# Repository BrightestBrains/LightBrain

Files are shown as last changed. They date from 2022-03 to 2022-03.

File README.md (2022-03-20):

# LightBrain

## Overview

The initial motivation was to develop a compact and relatively versatile light control device. Communicating with colleagues interested in electronics, I made a few design decisions so that the functionality would meet a number of requests: wide power supply voltages, protection, buttons, DMX support, shifted ouputs.

* ESP32-WROOM module
* four level shifted outputs
* 6-30V protected power input
* RS485 chip (DMX Support)
* Convinent buttons and user LED
* Very handy WAGO spring terminals

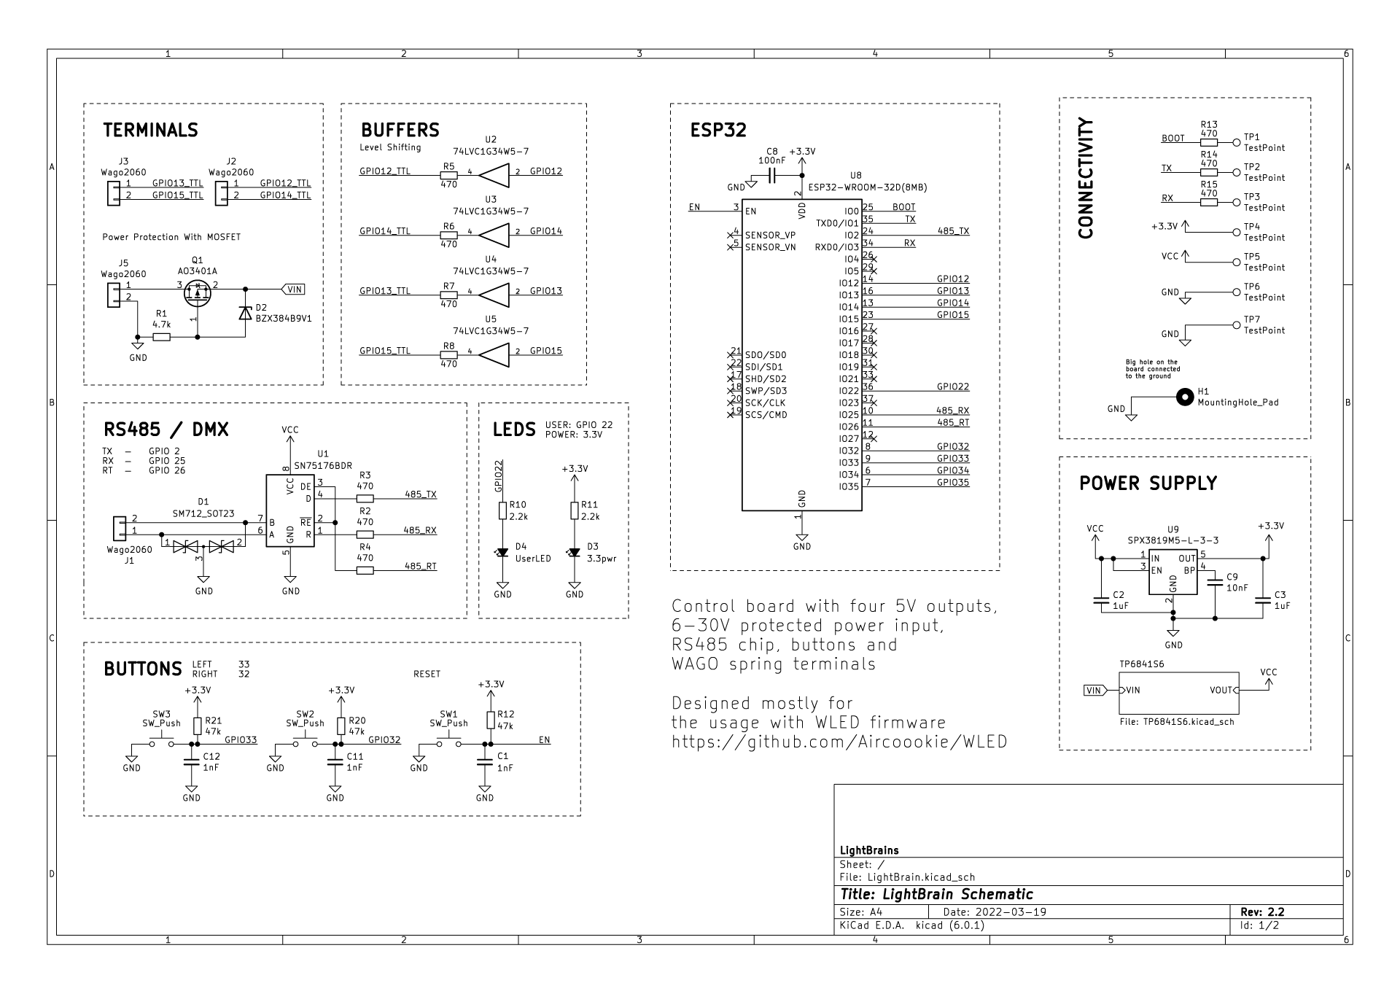
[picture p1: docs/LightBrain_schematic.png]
pcb schematic
 

## Usage

Designed mostly for the usage with [WLED firmware](https://github.com/Aircoookie/WLED) by [Aircookie](https://github.com/Aircoookie)

There is no USB=>UART bridge in design. This was done to make the design smaller and cheaper. In the future, a firmware device with pogopin will be made, but most likely there will be a revision of the entire design. WLED has OTA functionality which can be used in case of update the firmware.

The board comes with a few examples that I wrote to test the functionality of the board. I really like [micropython](https://micropython.org/), which works fine on these boards. Very handy for prototyping, the buttons and custom LED makes it interactive. Unfortunately, I never got around to running DMX with python. Then I wrote an example using the SparkFunDMX library, which works like a charm.

## Appearance and Examples

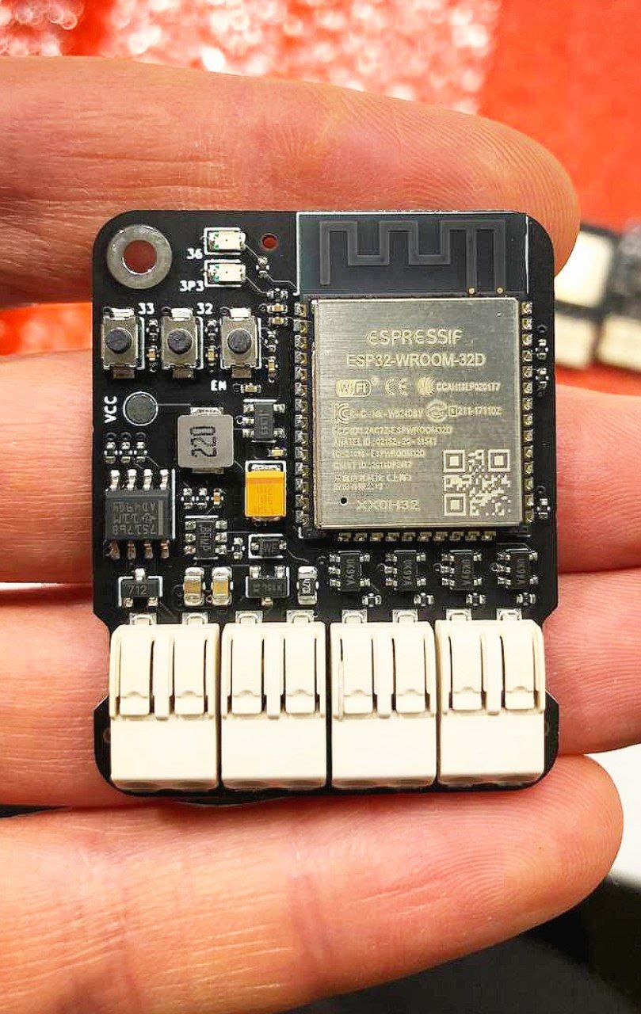
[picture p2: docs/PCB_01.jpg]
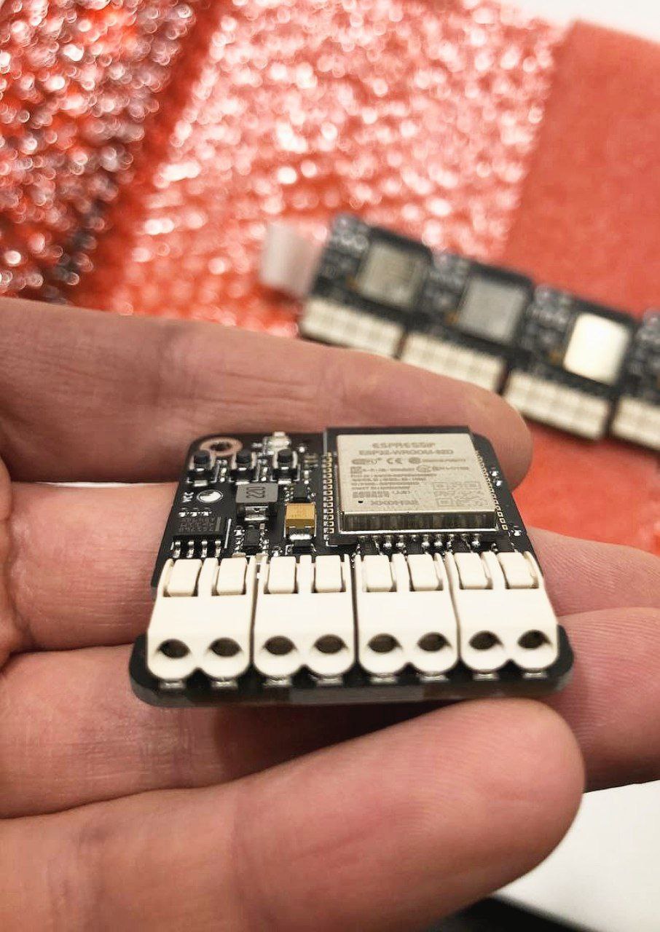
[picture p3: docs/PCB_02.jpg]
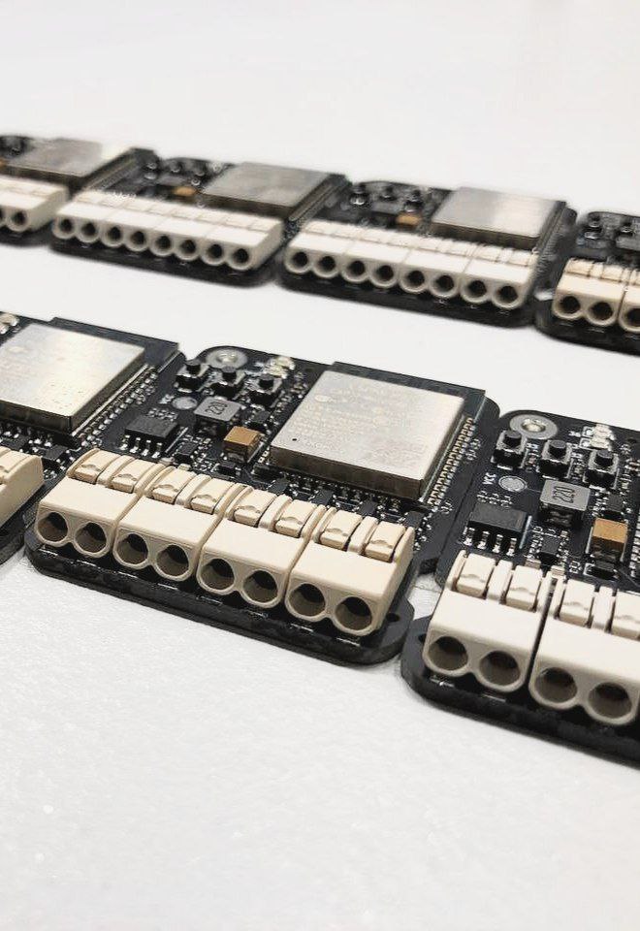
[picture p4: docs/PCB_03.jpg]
  

Illustration of working WLED:

https://user-images.githubusercontent.com/8849896/159166993-72adfaef-fdb5-461d-86bc-35848b8165a1.mp4

https://user-images.githubusercontent.com/8849896/159166995-e5065d50-ee23-4bfb-9fdf-d8251501cd79.mp4

https://user-images.githubusercontent.com/8849896/159166997-b3421e14-9344-47e1-aa16-2b2efedc7f29.mp4

Illustration of working DMX:

https://user-images.githubusercontent.com/8849896/159167005-f4b18b29-a19e-47f2-82c6-617aa11a5b83.mp4

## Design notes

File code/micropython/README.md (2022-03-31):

### Micropython

Over time, I have chosen for myself the best way to use micropython. It may not seem very convenient, but it is by far the most stable and consistent way to check code, to write a simple program.

I'm choosing [UPIOT](https://github.com/gepd/uPiotMicroPythonTool), Sublime plugin to develop with micropython. For all the details and more precise instructions, see the add-on's github.

MICROPYTHON INSTRUCTION:

1. Sublime — Package Package Control > Add Repository
2. Add Repository: https://rawgit.com/gepd/uPiot-MicroPython-Tool/master/repository.json
3. Package Control: Install Package > UPIOT
4. UPIOT: Download Firmware > esp32 > Put path to bin file and make sure that the link contains "http", not "https" (!)
5. UPIOT: Burn Firmware > esp32 > *.bin
6. It is better to erase the memory, respectively "press buttons" (EN + BOOT) - esptool will be waiting
7. UPIOT: Open Console (or in any other terminal)
8. UPIOT: Put Current File — main.py will start immediately after a reboot

Tips:
CTRL+SHIFT+P — fast menu for sublime.\
See the [Micropython](https://docs.micropython.org/en) documentation for more details.

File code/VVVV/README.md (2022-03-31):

### VVVV

VVVV is a general-purpose development tool with visual language capabilities. It is not only a tool for rapid prototyping and developing interactive software, but also a complete IDE based on .NET and C# technologies.

It's a bunch of proof of concepts and ingredients for future projects.

You can learn more on the website:\
visualprogrammin.net

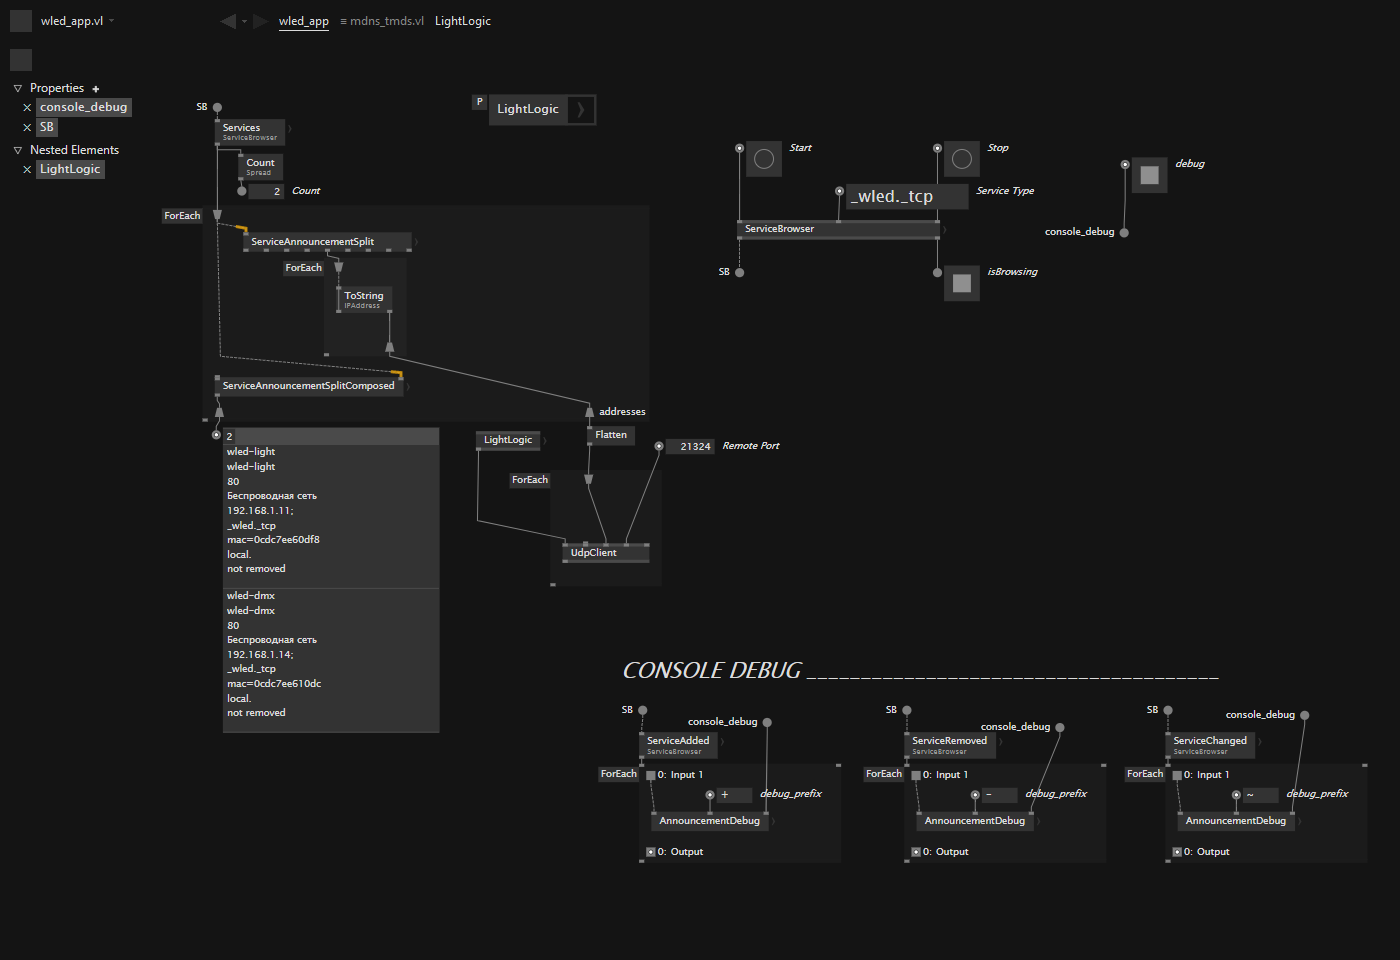
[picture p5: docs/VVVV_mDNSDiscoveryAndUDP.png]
VVVV


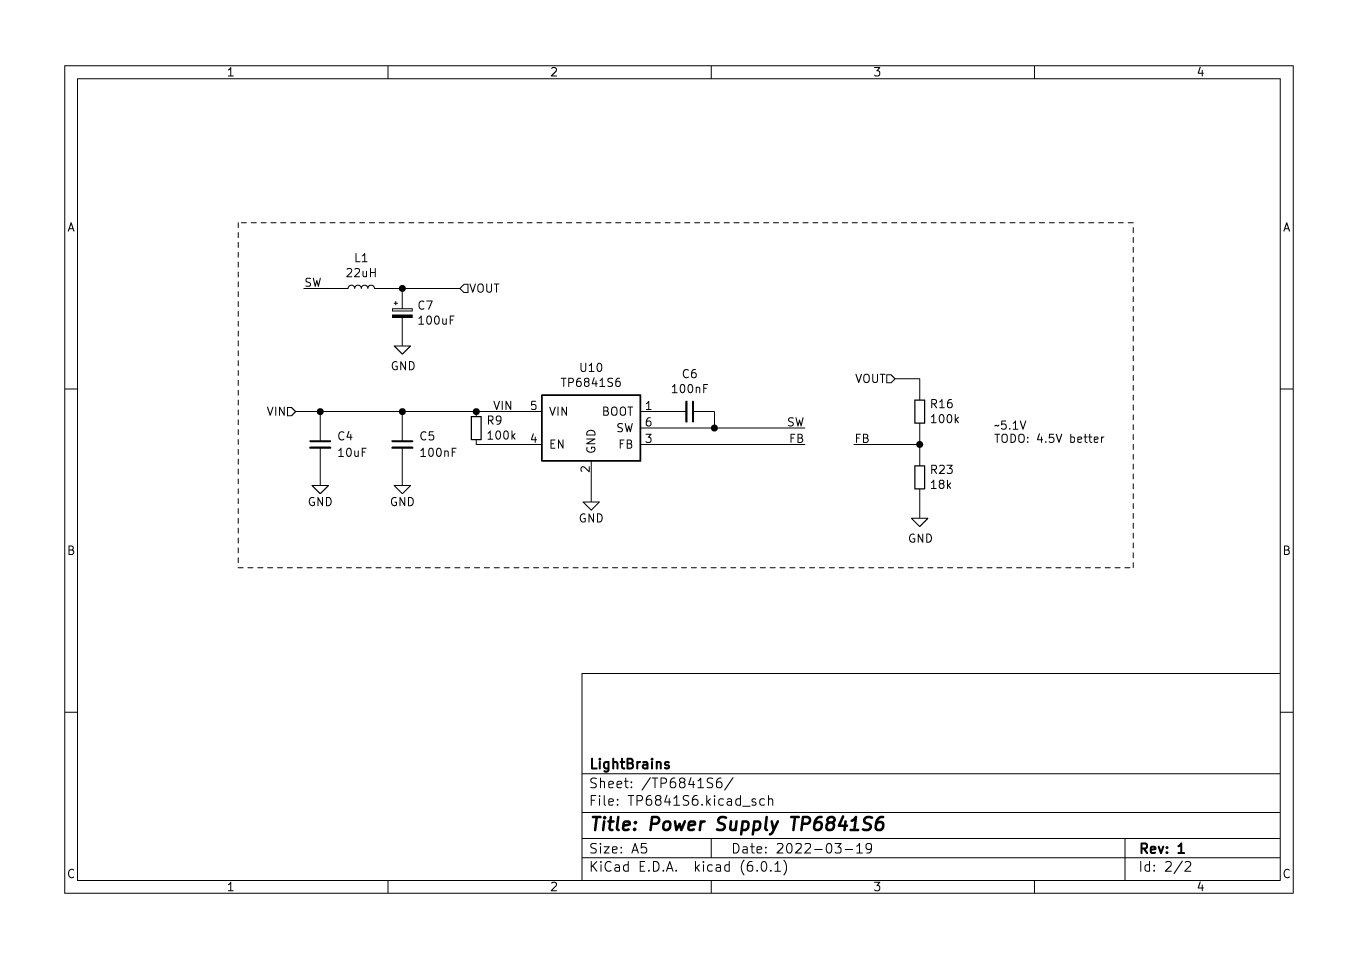
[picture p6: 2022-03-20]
docs/LightBrain_chematic_TP6841S6.png

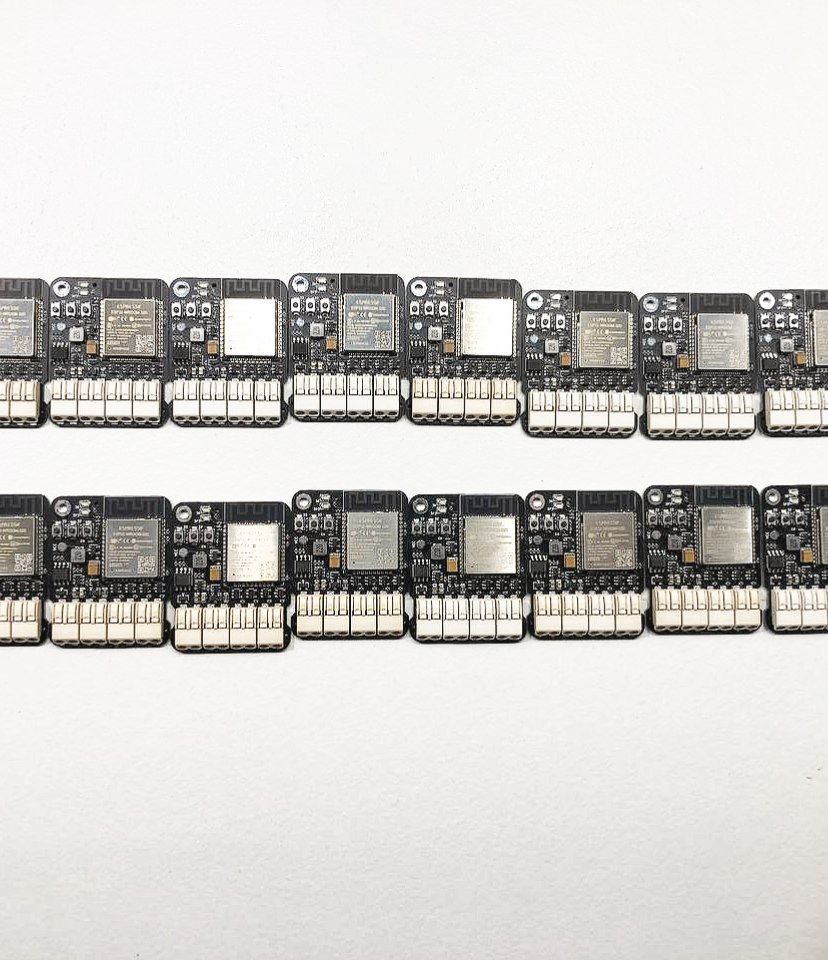
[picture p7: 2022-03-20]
docs/PCB_04.jpg

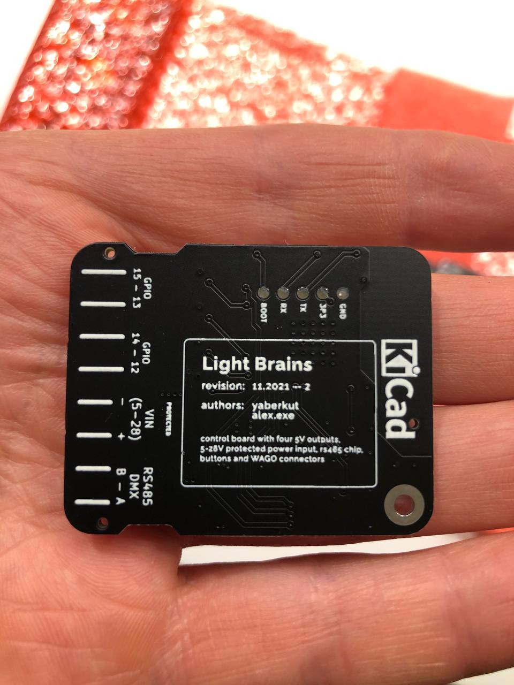
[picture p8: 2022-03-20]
docs/PCB_06.jpg

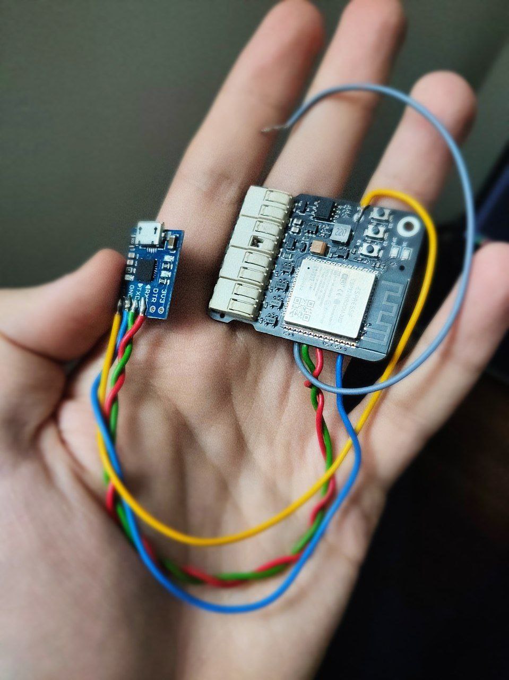
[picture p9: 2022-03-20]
docs/USB-UART-Connection.jpg

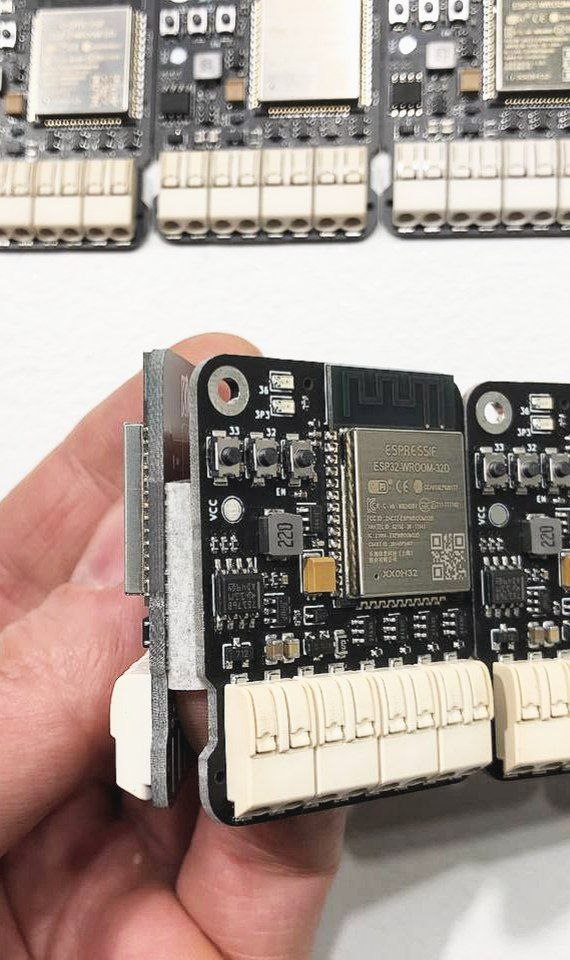
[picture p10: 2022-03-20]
docs/PCB_05.jpg

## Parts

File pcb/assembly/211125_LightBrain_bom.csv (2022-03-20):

Comment | Designator | Footprint | JLCPCB Part #
1nF Unpolarized capacitor, small symbol | C1,C11,C12 | C_0402_1005Metric | C1523
1uF Unpolarized capacitor, small symbol | C2,C3 | C_0402_1005Metric | C52923
10uF Unpolarized capacitor, small symbol | C4 | C_0805_2012Metric | C15850
100nF Unpolarized capacitor, small symbol | C5 | C_0805_2012Metric | C28233
100nF Unpolarized capacitor, small symbol | C6,C8 | C_0402_1005Metric | C307331
100uF Polarized capacitor, small symbol | C7 | CP_EIA-3528-21_Kemet-B | C115391
10nF Unpolarized capacitor, small symbol | C9 | C_0402_1005Metric | C15195
SM712_SOT23 7V/12V, 600W Asymmetrical TVS Diode Array, SOT-23 | D1 | SOT-23 | C2827658
BZX384B9V1 300mW Zener Diode, SOD-323 | D2 | D_SOD-323 | C241956
3.3pwr Light emitting diode, small symbol, filled shape | D3 | LED_0805_2012Metric | C2296
UserLED Light emitting diode, small symbol, filled shape | D4 | LED_0805_2012Metric | C2296
Wago2060 Generic connector, single row, 01x02, script generated (kicad-library-utils/schlib/autogen/connector/) | J1,J2,J3,J5 | Wago2060 | C2765055
22uH Inductor, small symbol | L1 | MWSA0402S | C408340
AO3401A -4.0A Id, -30V Vds, P-Channel MOSFET, SOT-23 | Q1 | SOT-23 | C15127
4.7k Resistor, small symbol | R1 | R_0805_2012Metric | C17673
470 Resistor, small symbol | R2,R3,R4,R5,R6,R7,R8,R13,R14,R15 | R_0402_1005Metric | C25117
100k Resistor, small symbol | R9,R16 | R_0402_1005Metric | C25741
2.2k Resistor, small symbol | R10,R11 | R_0402_1005Metric | C25879
47k Resistor, small symbol | R12,R20,R21 | R_0402_1005Metric | C25792
18k Resistor, small symbol | R23 | R_0402_1005Metric | C25762
SW_Push Push button switch, generic, two pins | SW1,SW2,SW3 | SW-SMD-2_2.9x3.9x1.7 | C843669
SN75176BDR Differential RS-422/RS-485 bus transceiver, SOIC-8 | U1 | SOIC-8_3.9x4.9mm_P1.27mm | C7063
74LVC1G34W5-7 Single Buffef Gate, Low-Voltage CMOS | U2,U3,U4,U5 | SOT25 | C526347
ESP32-WROOM-32D RF Module, ESP32-D0WDQ6 SoC, Wi-Fi 802.11b/g/n, Bluetooth, BLE, 32-bit, 2.7-3.6V, onboard antenna, SMD | U8 | ESP32-WROOM-32 | C473012
SPX3819M5-L-3-3 500mA Low drop-out regulator, Fixed Output 3.3V, SOT-23-5 | U9 | SOT-23-5 | C9055
TP6841S6 | U10 | SOT-23-6 | C2844736

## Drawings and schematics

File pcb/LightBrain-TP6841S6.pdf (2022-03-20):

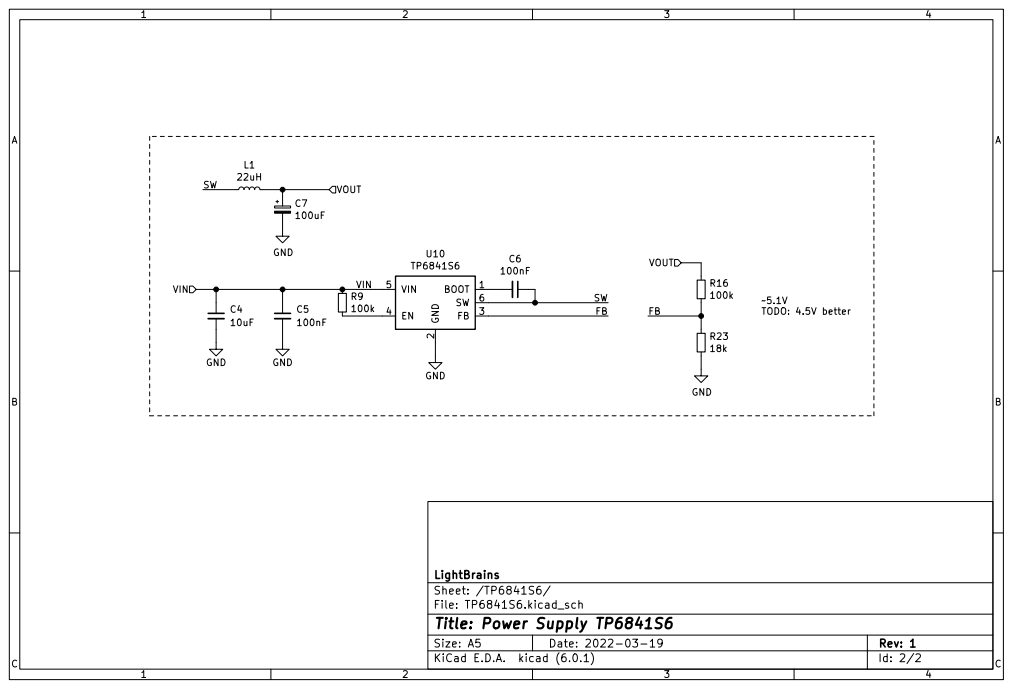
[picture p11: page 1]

2 FB 3 EN 4 VIN 5 SW 6 U10 TP6841S6 GND

Id: 2/2 Title: Power Supply TP6841S6

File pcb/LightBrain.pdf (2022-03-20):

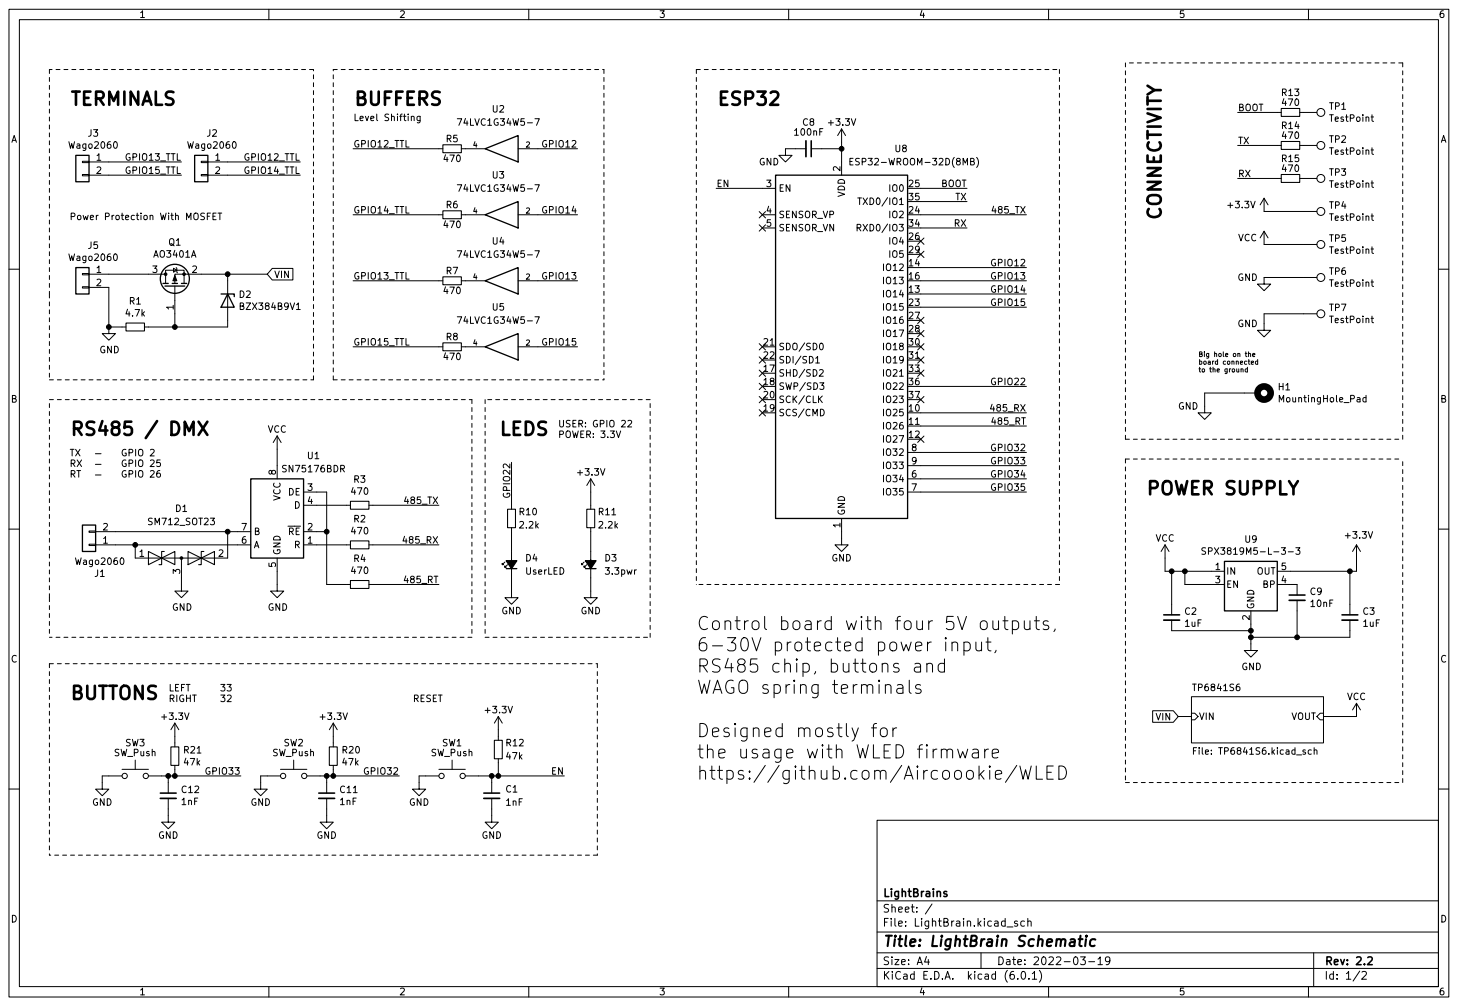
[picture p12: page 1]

470 GND
EN Designed mostly for

2 SCK/CLK 20 SDO/SD0 21 SDI/SD1 22

to the ground Power Protection With MOSFET

2 EN 3 BP 4 OUT 5 U9 SPX3819M5-L-3-3 GND GND GND

Big hole on the
board connected

LEDS USER: GPIO 22 POWER: 3.3V

Control board with four 5V outputs,
6-30V protected power input,
RS485 chip, buttons and
WAGO spring terminals

the usage with WLED firmware
https://github.com/Aircoookie/WLED

Id: 1/2 Title: LightBrain Schematic

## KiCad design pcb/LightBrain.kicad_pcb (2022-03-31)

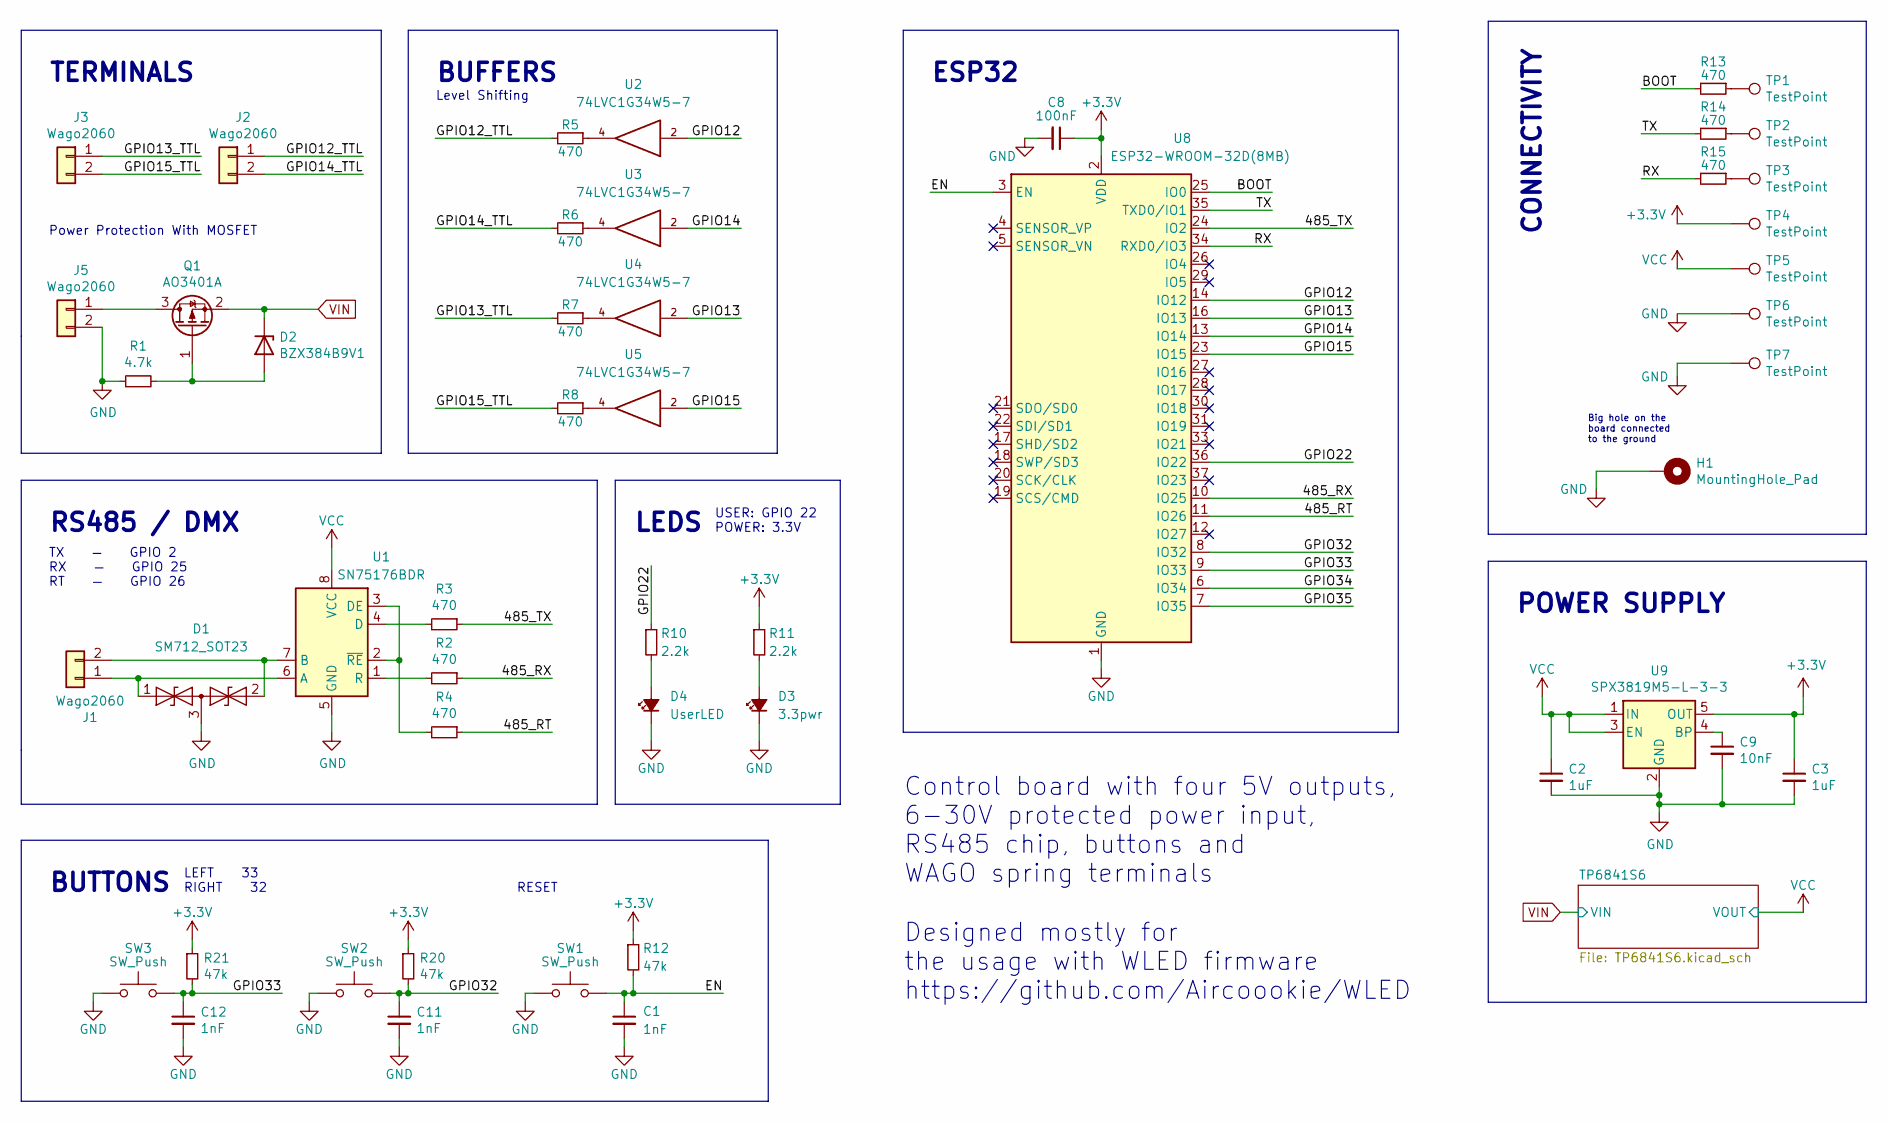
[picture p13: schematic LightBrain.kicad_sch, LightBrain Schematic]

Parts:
C1, C11, C12: 1nF; C_0402_1005Metric; JLCPCB Part # C1523
C2, C3: 1uF; C_0402_1005Metric; JLCPCB Part # C52923
C8: 100nF; C_0402_1005Metric; JLCPCB Part # C307331
C9: 10nF; C_0402_1005Metric; JLCPCB Part # C15195
D1: SM712_SOT23; SOT-23; JLCPCB Part # C32677
D2: BZX384B9V1; D_SOD-323; JLCPCB Part # C241956
D3: 3.3pwr; LED_0805_2012Metric; JLCPCB Part # C2296
D4: UserLED; LED_0805_2012Metric; JLCPCB Part # C2296
H1: MountingHole_Pad; MountingHole_2.5mm_Pad
J1, J2, J3, J5: Wago2060; JLCPCB Part # C2765055
Q1: AO3401A; SOT-23; JLCPCB Part # C15127
R1: 4.7k; R_0805_2012Metric; JLCPCB Part # C17673
R2, R3, R4, R5, R6, R7, R8, R13, R14, R15: 470; R_0402_1005Metric; JLCPCB Part # C25117
R10, R11: 2.2k; R_0402_1005Metric; JLCPCB Part # C25879
R12, R20, R21: 47k; R_0402_1005Metric; JLCPCB Part # C25792
SW1, SW2, SW3: SW_Push; SW-SMD-2_2.9x3.9x1.7; JLCPCB Part # C843669
TP1, TP2, TP3, TP4, TP5, TP6, TP7: TestPoint; TestPoint_My
U1: SN75176BDR; SOIC-8_3.9x4.9mm_P1.27mm; JLCPCB Part # C7063
U2, U3, U4, U5: 74LVC1G34W5-7; SOT25; JLCPCB Part # C526347
U8: ESP32-WROOM-32D(8MB); ESP32-WROOM-32; JLCPCB Part # C529577
U9: SPX3819M5-L-3-3; SOT-23-5; JLCPCB Part # C9055

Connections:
+3V3: C3.1, C8.1, R11.1, R12.1, R20.1, R21.1, TP4.1, U8.2 (VDD), U9.5 (OUT)
/485_RT: R4.1, U8.11 (IO26)
/485_RX: R2.1, U8.10 (IO25)
/485_TX: R3.1, U8.24 (IO2)
/BOOT: R13.2, U8.25 (IO0)
/GPIO12: U2.2, U8.14 (IO12)
/GPIO12_TTL: J2.1, R5.2
/GPIO13: U4.2, U8.16 (IO13)
/GPIO13_TTL: J3.1, R7.2
/GPIO14: U3.2, U8.13 (IO14)
/GPIO14_TTL: J2.2, R6.2
/GPIO15: U5.2, U8.23 (IO15)
/GPIO15_TTL: J3.2, R8.2
/GPIO32: C11.1, R20.2, SW2.2, U8.8 (IO32)
/GPIO33: C12.1, R21.2, SW3.2, U8.9 (IO33)
/GPIO34: U8.6 (IO34)
/GPIO35: U8.7 (IO35)
/GPIO36: R10.1, U8.36 (IO22)
/RX: R15.2, U8.34 (RXD0/IO3)
/TX: R14.2, U8.35 (TXD0/IO1)
GND: C1.2, C2.2, C3.2, C8.2, C9.2, C11.2, C12.2, D1.3 (common), D3.1 (K), D4.1 (K), H1.1, J5.2, R1.1, SW1.1, SW2.1, SW3.1, TP6.1, TP7.1, U1.5 (GND), U2.3 (GND), U3.3 (GND), U4.3 (GND), U5.3 (GND), U8.1 (GND), U8.15 (GND), U8.38 (GND), U8.39 (GND), U9.2 (GND); also elsewhere on the board
unnamed: C1.1, R12.2, SW1.2, U8.3 (EN)
unnamed: C9.1, U9.4 (BP)
unnamed: D1.1 (A1), J1.1, U1.6 (A)
unnamed: D1.2 (A2), J1.2, U1.7 (B)
unnamed: D2.2 (A), Q1.1 (G), R1.2
unnamed: D3.2 (A), R11.2
unnamed: D4.2 (A), R10.2
unnamed: J5.1, Q1.3 (D)
unnamed: R2.2, U1.1 (R)
unnamed: R3.2, U1.4 (D)
unnamed: R4.2, U1.2 (~RE), U1.3 (DE)
unnamed: R5.1, U2.4
unnamed: R6.1, U3.4
unnamed: R7.1, U4.4
unnamed: R8.1, U5.4
unnamed: R13.1, TP1.1
unnamed: R14.1, TP2.1
unnamed: R15.1, TP3.1
VCC: C2.1, TP5.1, U1.8 (VCC), U2.5 (VCC), U3.5 (VCC), U4.5 (VCC), U5.5 (VCC), U9.1 (IN), U9.3 (EN); also elsewhere on the board
VIN: D2.1 (K), Q1.2 (S); also elsewhere on the board

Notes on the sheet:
TERMINALS
ESP32
LEDS
Level Shifting
RESET
RS485 / DMX
Designed mostly for the usage with WLED firmware https://github.com/Aircoookie/WLED
BUFFERS
BUTTONS
Control board with four 5V outputs, 6-30V protected power input, RS485 chip, buttons and WAGO spring terminals
Power Protection With MOSFET
USER: GPIO 22 POWER: 3.3V
POWER SUPPLY
TX — GPIO 2 RX — GPIO 25 RT — GPIO 26
LEFT 33 RIGHT 32
Big hole on the board connected to the ground
CONNECTIVITY

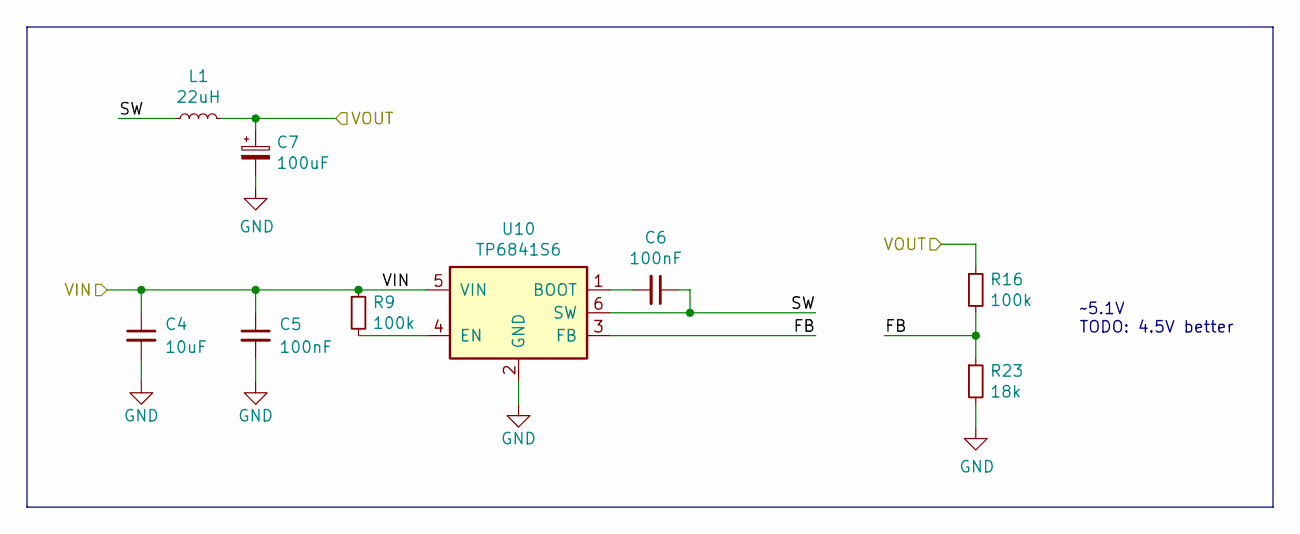
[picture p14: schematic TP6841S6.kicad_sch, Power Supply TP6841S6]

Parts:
C4: 10uF; C_0805_2012Metric; JLCPCB Part # C15850
C5: 100nF; C_0805_2012Metric; JLCPCB Part # C28233
C6: 100nF; C_0402_1005Metric; JLCPCB Part # C307331
C7: 100uF; CP_EIA-3528-21_Kemet-B; JLCPCB Part # C115391
L1: 22uH; MWSA0402S; JLCPCB Part # C408340
R9, R16: 100k; R_0402_1005Metric; JLCPCB Part # C25741
R23: 18k; R_0402_1005Metric; JLCPCB Part # C25762
U10: TP6841S6; SOT-23-6; JLCPCB Part # C2844736

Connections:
/TP6841S6/FB: R16.2, R23.1, U10.3 (FB)
/TP6841S6/SW: C6.1, L1.1, U10.6 (SW)
GND: C4.2, C5.2, C7.2, R23.2, U10.2 (GND); also elsewhere on the board
unnamed: C6.2, U10.1 (BOOT)
unnamed: R9.2, U10.4 (EN)
VCC: C7.1, L1.2, R16.1; also elsewhere on the board
VIN: C4.1, C5.1, R9.1, U10.5 (VIN); also elsewhere on the board

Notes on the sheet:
~5.1V TODO: 4.5V better

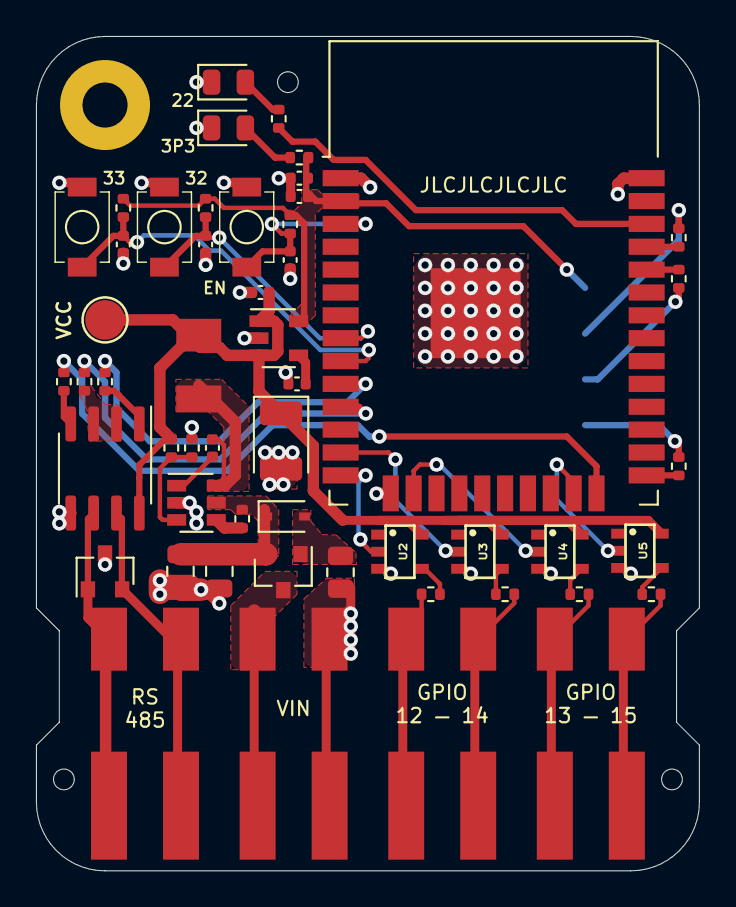
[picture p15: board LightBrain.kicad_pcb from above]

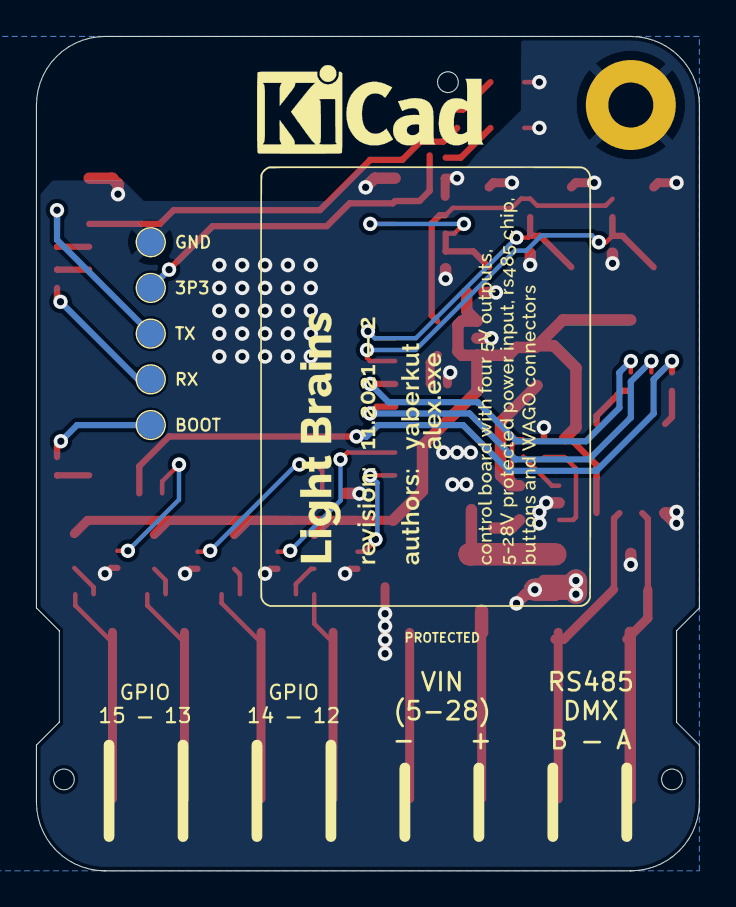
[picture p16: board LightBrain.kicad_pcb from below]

Board: 2 copper layers, 36.8 x 46.4 mm, 58 parts (5 on the bottom side), 43 nets.

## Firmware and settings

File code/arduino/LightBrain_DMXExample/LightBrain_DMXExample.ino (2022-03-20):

/*
Simple example to try DMX capability
Press a button to cycle through values
Current value will be shown as user LED brightness and will be sent to DMX
*/

#include "src/SparkFunDMX.h"
#define LED 22

SparkFunDMX dmx;
volatile byte value_index = 0;
byte values[] = {0, 1, 16, 32, 127, 255};

void setup() {
  
  pinMode(LED, OUTPUT);
  
  pinMode(26, OUTPUT); //rs485 rt lightbrain
  digitalWrite(26, LOW); //rs485 rt lightbrain
  
  pinMode(32, INPUT_PULLUP); //button
  pinMode(33, INPUT_PULLUP); //button

  attachInterrupt(digitalPinToInterrupt(32), button32, FALLING);
  attachInterrupt(digitalPinToInterrupt(33), button33, FALLING);

  ledcSetup(0, 5000, 13);
  ledcAttachPin(LED, 0);

  dmx.initWrite(5);
  delay(20);
}

void ledcAnalogWrite(uint8_t channel, uint32_t value, uint32_t valueMax = 255) {
  // calculate duty, 8191 from 2 ^ 13 - 1
  uint32_t duty = (8191 / valueMax) * min(value, valueMax);
  // write duty to LEDC
  ledcWrite(channel, duty);
}

void loop() {
  byte value = values[value_index];
  ledcAnalogWrite(0, value);

  // ***dmx send ***
  dmx.write(1, value);
  dmx.write(2, value);
  dmx.write(3, value);
  dmx.update();
}

void button32(){
  changeLightValues(1);
}

void button33(){
  changeLightValues(-1);
}

void changeLightValues(int dir) {
  int count = sizeof(values);
  if (dir>0) {
    value_index = (count + value_index + 1) % count;
  } else if (dir<0) {
    value_index = (count + value_index - 1) % count;
  }
}

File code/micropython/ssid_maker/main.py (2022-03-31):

'''
SSSID maker
Makes wifi networks
with a name from a file with a specified interval
'''
import machine
import time
import network
import uasyncio
import random
import os
from machine import Pin, reset
from network import WLAN

led = Pin(22, Pin.OUT)

def buttons_setup():
    print("_ buttons setup _\n")
    Button32 = Pin(32, Pin.IN, Pin.PULL_UP)
    Button33 = Pin(33, Pin.IN, Pin.PULL_UP)
    Button32.irq(trigger=Pin.IRQ_RISING, handler=button_right)
    Button33.irq(trigger=Pin.IRQ_RISING, handler=button_left)

def button_right(pin):
    print(pin.id)
    pass

def button_left(pin):
    print(pin)
    pass

buttons_setup()

# read filesystem and select first *.txt file to read
print("_ text preparation _\n")
texts = []
for file in os.listdir():
    if file.endswith(".txt"):
        texts.append(file)
f = open(texts[0])
rows = f.read().split("\n")
count = len(rows) - 1
f.close()

tokens = []
for row in rows:
    words = row.split(" ")

current_row = 0

def makeSSID():
    global rows, current_row
    led.on()
    name = rows[current_row]
    print(name)
    ap = WLAN(network.AP_IF)
    ap.config(essid=name)
    ap.active(True)
    current_row = (current_row + 1) % count
    led.off()

async def SSIDmaker():
    while True:
        makeSSID()
        await uasyncio.sleep(8)

uasyncio.run(SSIDmaker())

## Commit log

2022-03-20 Added: Code PCB files Initial structure
    [211125_LightBrain_Positions.csv, 211125_LightBrain_bom.csv, LightBrain.kicad_pcb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]
2022-03-20 Doc files, slight fixes, initial readme.md content
    [LightBrain.kicad_sch, TP6841S6.kicad_sch]
2022-03-31 More examples: vvvv, micropython; fix in gerbers; added firmware binary
    [LightBrain.kicad_pcb]
2022-04-21 add missing footprints pretty
